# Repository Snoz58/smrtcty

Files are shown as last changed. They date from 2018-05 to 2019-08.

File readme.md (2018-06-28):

Smart Village
=============

Définition
----------

Ce projet a pour objectif la réalisation d'un système de « Smart City » à l’échelle d’un village.

Il est Open source, et basé sur le plus d'éléments open source possible, côté matériel comme logiciel.

Cette solution se présente sous la forme d'un « kit », réplicable, simple à mettre en place et à utiliser, et polyvalent.

Node / Noeuds
-------------

Cette partie du système est totalement indépendante. Il s'agit de points de relevé d'informations auto alimentés (panneau photovoltaïque) basés autour d'une carte Arduino qui transmet les données collectées par l'intermédiaire d'une liaison sans fil.

Ces nœuds permettent le captage d’information dans l’environnement (pour la version en cours de développement des capteurs concernant la qualité de l’air (Température, Pression, Humidité, Particules...) mais aussi des capteurs plus orientés qualité de l’eau (Température, Ph, niveau…).

Passerelle
----------
La passerelle centralise les informations qu’elle reçoit de la part des différents nœuds.
Elle se présente sous la forme d'un Raspberry Pi associé à un module sans fil, installé dans un bâtiment afin de bénéficier d’un accès internet et d’une alimentation électrique. Elle va récupérer les données des capteurs, et les renvoyer vers une base de donnée distante.

Plateforme de centralisation
----------------------------

Cette dernière partie du système n’est pas matérielle mais logicielle, il s’agit d’un système de tableau de bord qui va permettre de visualiser les données recueillies par le dispositif sous forme de tableau et de graphique.

Transmission Sans Fil
---------------------
Les solutions de transmission de donnée retenues pour ce projet sont toutes basées sur des technologies radio :
 * Radio « standard » 433MHz (appareils domotique, etc).
 * xBee / ZigBee.
 * LoRa, dérivé également de la technologie radio, orienté basse consommation longue portée.

Solution de transmission sans fil sera choisie en fonction des résultat obtenus lors des tests de portée et de la situation dans laquelle le système sera mis en place.

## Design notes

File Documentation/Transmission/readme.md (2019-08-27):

## Transmission sans fil

### LoRa

---

***[DOCUMENTATION MODULE ADAFRUIT RFM95W](./RFM95W.md)***

Documentation module RFM95W (ref 3072) :
https://learn.adafruit.com/adafruit-rfm69hcw-and-rfm96-rfm95-rfm98-lora-packet-padio-breakouts/using-the-rfm69-radio

Autres infos :
https://forum.arduino.cc/index.php?topic=471254.0

---

Exemples / docmentation Python :
https://learn.adafruit.com/adafruit-rfm69hcw-and-rfm96-rfm95-rfm98-lora-packet-padio-breakouts?view=all

Intro technologie LoRa (cartes, topologie, outils, ...) :
http://www.instructables.com/id/Introducing-LoRa-/

Documentation expérimentation LoRa / tests de portée :
https://www.cooking-hacks.com/documentation/tutorials/extreme-range-lora-sx1272-module-shield-arduino-raspberry-pi-intel-galileo/

Cartes spécifiques LoRa campatibles Arduino / Raspberry :
https://www.cooking-hacks.com/documentation/tutorials/lorawan-for-arduino-raspberry-pi-waspmote-868-900-915-433-mhz/

Infos LoRaWAN / Sigfox :
https://forum.arduino.cc/index.php?topic=503808.0

### xBee

---

***[DOCUMENTATION MODULE xBee](./xBee.md)***

Documentation paramétrage / utilisation logiciel XCTU :

http://www.electro-info.ovh/index.php?id=231
https://learn.sparkfun.com/tutorials/exploring-xbees-and-xctu
http://www.libelium.com/development/waspmote/documentation/x-ctu-tutorial/
https://www.digi.com/resources/documentation/Digidocs/90001456-13/tasks/t_wk_configure_xbees.htm

---

Communication longue distance avec xBee :
https://electronics.stackexchange.com/questions/1149/wireless-communication-over-long-distances

Guide modules xBee avec spécifications :
https://www.sparkfun.com/pages/xbee_guide

### Radio

---

***[DOCUMENTATION MODULE HC-12](./hc-12.md)***

Tutoriel d'utilisation du module + exemples :
https://howtomechatronics.com/tutorials/arduino/arduino-and-hc-12-long-range-wireless-communication-module/

Video + ressource commandes AT :
https://www.instructables.com/id/Long-Range-18km-Arduino-to-Arduino-Wireless-Commun/

---

***[DOCUMENTATION MODULE NRF24L01](./NRF24L01.md)***

Tutoriel d'utilisation du module + exemples :
https://howtomechatronics.com/tutorials/arduino/arduino-wireless-communication-nrf24l01-tutorial/

---

### Autres

Guide modules Bluetooth avec spécifications :
https://www.intorobotics.com/pick-right-bluetooth-module-diy-arduino-project/

Transformation int to char :
https://www.instructables.com/id/Converting-integer-to-character/

## Transmission Filaire

Communication série Arduino <-> Raspberry :
http://www.instructables.com/id/Raspberry-Pi-Arduino-Serial-Communication/

Communication Arduino <-> Raspberry sur le bus I2C :
https://www.pihomeserver.fr/2013/08/13/raspberry-pi-home-server-arduino-lier-les-deux-via-bus-i2c/

Communication Arduino <-> Raspberry via UART :
https://electrosome.com/uart-raspberry-pi-python/

# Infos Passerelle Raspberry Pi

Wiki dragino :
https://wiki.dragino.com/index.php?title=Lora_Shield

Dragino Shield cs pin :
https://www.google.fr/search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:

Gpio Python :
https://deusyss.developpez.com/tutoriels/RaspberryPi/PythonEtLeGpio/

Tuto gateway sans shield :
https://www.hackster.io/ChrisSamuelson/lora-raspberry-pi-single-channel-gateway-cheap-d57d36

Programme passerelle en C :
https://github.com/dragino/rpi-lora-tranceiver/blob/master/dragino_lora_app_w1/main.c

LoRa GPS hat wiki dragino :
https://wiki.dragino.com/index.php?title=Lora/GPS_HAT#Two_RPI_use_LoRa_to_transmit

Programme Gateway :
https://github.com/CongducPham/LowCostLoRaGw

LoRa Shield pour Arduino :
https://wiki.dragino.com/index.php?title=Lora_Shield

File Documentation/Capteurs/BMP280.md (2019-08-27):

# BMP280
Capteur de pression atmosphérique - Baromètre

## Programme

Nom du programme : BMP280.ino

```C++
#include "Seeed_BMP280.h"
#include <Wire.h>

BMP280 bmp280;

void setup()
{
  Serial.begin(9600);
  if(!bmp280.init()) {
    Serial.println("Device not connected or broken!");
  }
}

void loop()
{

  float p = bmp280.getPressure();
  float t = bmp280.getTemperature();

  Serial.print("Temp: ");
  Serial.print(t);

  Serial.print("Pressure: ");
  Serial.println(p);

  delay(1000);
}
```
## Ressources

http://gilles.thebault.free.fr/spip.php?article47

http://idehack.com/blog/tutoriel-arduino-bmp280/

https://www.tala-informatique.fr/wiki/index.php/Arduino_BMP280

https://create.arduino.cc/projecthub/SurtrTech/bmp280-measure-temperature-pressure-and-altitude-e1c857

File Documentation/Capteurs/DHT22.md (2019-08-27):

# DHT22
Cateur de température et d'humidité

## Programme :

Nom du programme : DHT21.ino
```C++
#include <Adafruit_Sensor.h>
#include <DHT.h>
#include <DHT_U.h>

#define DHTPIN            A2
#define DHTTYPE           DHT22

DHT_Unified dht(DHTPIN, DHTTYPE);

void setup() {
  Serial.begin(9600);
  dht.begin();
}

void loop() {
  // Delay between measurements.
  delay(1000);

  sensors_event_t event;  
  dht.temperature().getEvent(&event);
  if (isnan(event.temperature)) {
    Serial.println("Error reading temperature!");
  }
  else {
    Serial.print("Temperature: ");
    Serial.print(event.temperature);
    Serial.println(" *C");
  }

  // Get humidity event and print its value.
  dht.humidity().getEvent(&event);
  if (isnan(event.relative_humidity)) {
    Serial.println("Error reading humidity!");
  }
  else {
    Serial.print("Humidity: ");
    Serial.print(event.relative_humidity);
    Serial.println("%");
  }
}
```
## Ressources :

http://www.manuel-esteban.com/lire-une-sonde-dht22-avec-un-arduino/

https://projetsdiy.fr/mesure-humidite-temperature-capteur-dht11-dht22-arduino-raspberry/

http://nagashur.com/blog/2013/06/18/lire-la-valeur-dune-sonde-de-temperature-et-d%E2%80%99hygrometrie-dht11/

https://www.carnetdumaker.net/articles/utiliser-un-capteur-de-temperature-et-dhumidite-dht11-dht22-avec-une-carte-arduino-genuino/

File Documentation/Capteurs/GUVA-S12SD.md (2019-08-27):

# GUVA-S12SD
Capteur UV

## Programme
Nom du programme : GUVA-S12SD.ino

```C++
void setup()
{
  Serial.begin(9600);
}

void loop()
{
  float sensorVoltage;
  float sensorValue;

  sensorValue = analogRead(A1);
  sensorVoltage = sensorValue/1024*3.3;
  Serial.print("sensor reading = ");
  Serial.print(sensorValue);
  Serial.println("");
  Serial.print("sensor voltage = ");
  Serial.print(sensorVoltage);
  Serial.println(" V");
  delay(3000);
}
```

## Ressources

https://www.adafruit.com/product/1918

https://forums.adafruit.com/viewtopic.php?f=19&t=95381

https://cdn-shop.adafruit.com/datasheets/1918guva.pdf

http://arduinolearning.com/code/arduino-guva-s12sd-uv-sensor.php

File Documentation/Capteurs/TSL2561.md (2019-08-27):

# TSL2561
Lux sensor / Capteur de luminosité

## Programme

Nom du programme : TSL2561.ino
```C++
#include <Wire.h>
#include <Adafruit_Sensor.h>
#include <Adafruit_TSL2561_U.h>

Adafruit_TSL2561_Unified tsl = Adafruit_TSL2561_Unified(TSL2561_ADDR_FLOAT, 12345);

void setup(void)
{
  Serial.begin(9600);  

  tsl.begin();

  tsl.enableAutoRange(true);            
  tsl.setIntegrationTime(TSL2561_INTEGRATIONTIME_101MS);  

}

void loop(void)
{  

  sensors_event_t event;
  tsl.getEvent(&event);

  Serial.print(event.light); Serial.println(" lux");

  delay(250);
}
```

## Ressources
https://learn.adafruit.com/tsl2561/arduino-code

https://github.com/adafruit/Adafruit_TSL2561

https://fr.wikipedia.org/wiki/Lux_(unit%C3%A9)

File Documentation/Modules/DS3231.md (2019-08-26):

https://github.com/jarzebski/Arduino-DS3231/blob/master/DS3231_alarm/DS3231_alarm.ino

http://www.open-sensing.org/lorablog/2017/10/23/low-power-rtc-and-sleeping-processors-a-guided-walkthrough

https://github.com/JChristensen/DS3232RTC

https://forum.arduino.cc/index.php?topic=139955.0

https://forum.arduino.cc/index.php?topic=346940.75

https://forum.arduino.cc/index.php?topic=404942.0

https://forum.arduino.cc/index.php?topic=319975.0

https://forum.sparkfun.com/viewtopic.php?t=40332

https://thecavepearlproject.org/2014/05/21/using-a-cheap-3-ds3231-rtc-at24c32-eeprom-from-ebay/

https://forum.arduino.cc/index.php?topic=241491.0

https://thekurks.net/blog/2018/2/5/wakeup-rtc-datalogger

https://learn.adafruit.com/adafruit-ds3231-precision-rtc-breakout?view=all

https://arduino.stackexchange.com/questions/10516/rtc-square-wave/10561

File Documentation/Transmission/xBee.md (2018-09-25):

# XBee

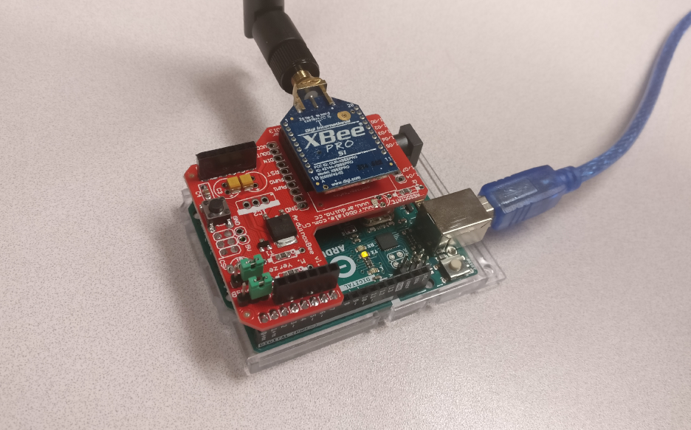
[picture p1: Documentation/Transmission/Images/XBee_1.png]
module xBee


## Paramétrage :

Les modules xBee sont différents des autres modules utilisées jusqu'à présent, ils possèdent en effet une mémoire et un firmware spécifique, avec des adresses.

Pour la configuration de ces modules, il est nécessaire d'utiliser le logiciel XCTU, fourni par DIGI (producteur des modules xBee)

Le logiciel est disponible [ici](https://www.digi.com/support/productdetail?pid=3352) dans la section ***Diagnostics,Utilities and MIBs***

* XCTU version 6.4.0 (dernière version en date)
* Legacy XCTU, version 5.2.8.6 (génération précédente)

## Problèmes rencontrés :

La plupart des tutoriels utilisent un [USB explorer ](https://www.sparkfun.com/products/11812) pour connecter le xBee à l'ordinateur. Ne possédans pas cet appareil, j'ai donc utilisé une carte arduino ([UNO](https://www.sparkfun.com/products/11021) et [MEGA](https://www.sparkfun.com/products/11061)) associé à un [shield xbee](https://www.gotronic.fr/art-module-xbee-shield-12427.htm).

J'ai donc commencé mes tests avec XCTU V6.4.0 et le module xBee connecté au shield sur l'Arduino MEGA.

La découverte des modules connecté au pc est possible avec le second bouton en haut à gauche de l'écran :

bouton discover xctu

Une popup s'ouvre alors en listant les ports COM disponibles, on selectionne celui correspondant à l'Arduino avant de cliquer sur *Next* :

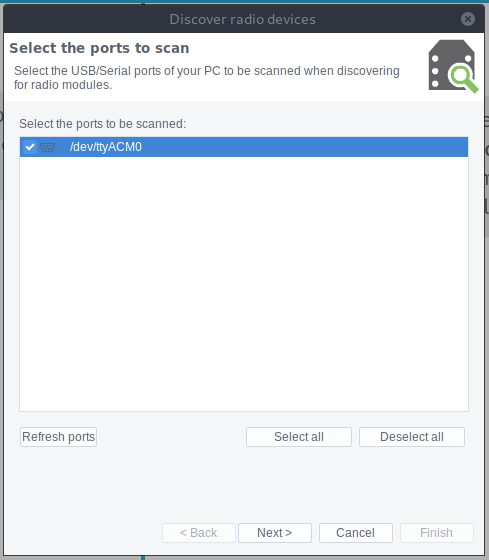
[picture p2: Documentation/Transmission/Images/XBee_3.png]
popup discover xctu


S'ouvrent alors les paramètres de recherche des modules, et on peut cliquer sur *Finish* pour lancer la recherche :

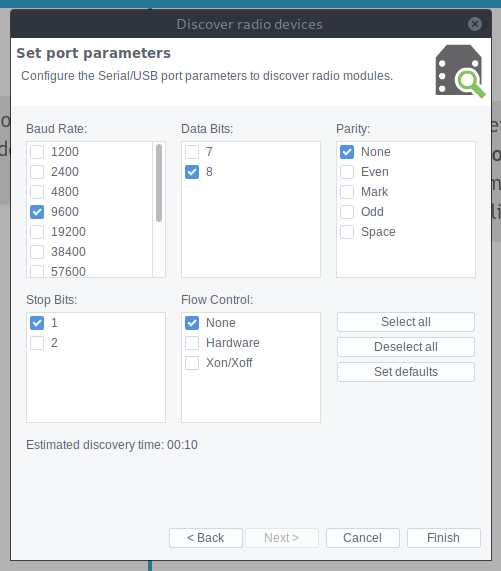
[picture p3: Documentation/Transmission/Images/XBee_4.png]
port parameters xctu


Le module devrait alors apparaître sur le côté gauche de l'écran :

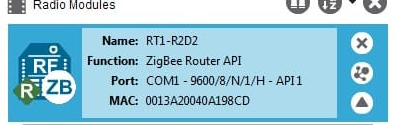
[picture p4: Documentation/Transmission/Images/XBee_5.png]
module xctu


*** Premier problème : ***

À ce moment, la carte Arduino et le module associé sont donc reconnus par le logiciel, mais les paramètres internes ne le sont pas encore, on sélectionne donc l'option *Read* :

Read xctu

Une pop up s'affiche alors en demandant de reset notre module radio :

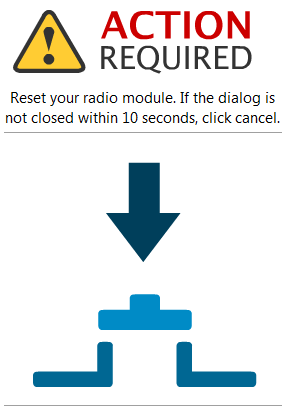
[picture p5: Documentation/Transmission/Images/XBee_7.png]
action required xctu


Cependant, ni le bouton reset ni le bouton présent sur le shield ne permettent de débloquer cet écran.

Après avoir suivi [ce tuto](https://learn.sparkfun.com/tutorials/exploring-xbees-and-xctu/troubleshooting#reset) pour reset un module xBee en connectant le pin 5 (reset) au pin 10 (GND). La LED présente sur le shield s'éteint puis se rallume, indiquant le reset du module, mais la popup reste cependant, jusqu'à se transformer en message d'erreur au bout d'un certain temps.

Apres recherche, il s'avère que les versions précédentes du logiciel ne nécessitent pas cette action, j'ai donc tenté de l'utiliser avec l'aide de [ce tuto](https://robotic-controls.com/book/export/html/14) d'utiliser la version "legacy" de xctu.

La carte Arduino sans son microcontrolleur a donc été couplé au shield dont les jumpers sont passés en mode *USB* :

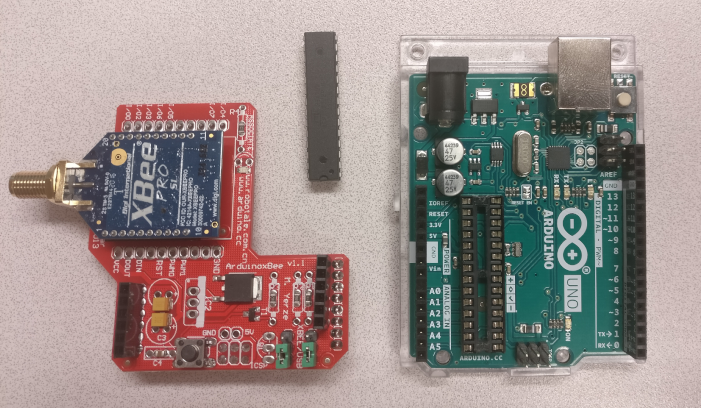
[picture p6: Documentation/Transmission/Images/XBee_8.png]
Uno sans uc


Sur le logiciel, la carte Arduino est bien reconnue par le logiciel:

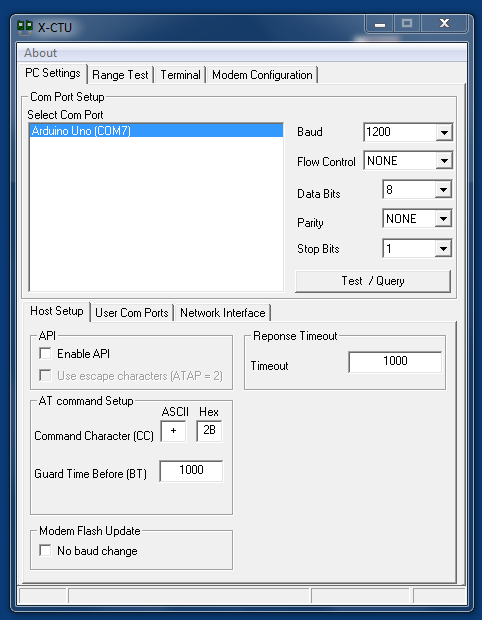
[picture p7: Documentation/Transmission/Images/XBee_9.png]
old xctu


Après avoir cliqué sur le bouton *Test / Query*  le logiciel reconnaît bien la carte et le module xBee.

Je débranche donc le montage pour le réutiliser avec le logiciel récent.

*** Deuxième problème ***

Sur le "nouveau" xctu, à la fin de la recherche de module xBee, après avoir correctement sélectionné le bon port, aucun module xBee n'est trouvé, ou bien une erreur apparaît indiquant un timeout sans que le logiciel n'ait pu récupérer les informations de la carte :

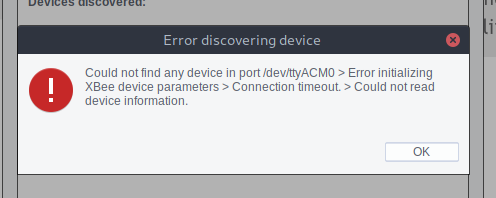
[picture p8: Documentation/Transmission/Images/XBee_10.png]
module xBee


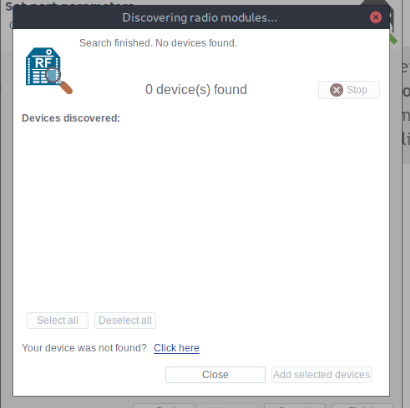
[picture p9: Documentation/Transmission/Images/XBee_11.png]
module xBee


De retour sur la version Legacy de xctu, le logiciel nous demande maintenant de reset le module xBee. Comme relevé dans le premier problème, même en connectant le pin RST à la masse, le logiciel ne se débloque pas comme il devrait :

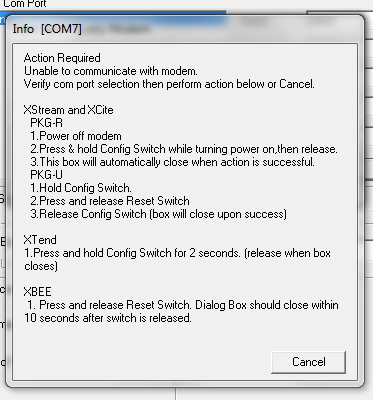
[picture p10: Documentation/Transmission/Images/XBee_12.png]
module xBee


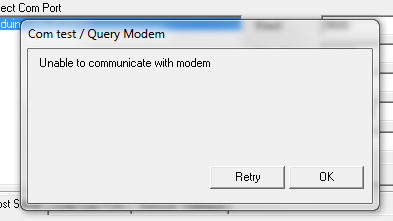
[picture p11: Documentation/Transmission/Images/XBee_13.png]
module xBee


Au final, avec la carte Arduino MEGA, ou avec la carte Arduino UNO, avec ou sans microcontrôleur, avec les jumpers en mode USB ou xBee, et sur les deux logiciels, le résultat est le même : aucune connexion n'est possible entre le logiciel et le module xBee.
J'ai également essayé avec un troisième module xBee, qui ne m'avait pas encore servi, et le résultat est resté le même.  

## xBee USB Adapter

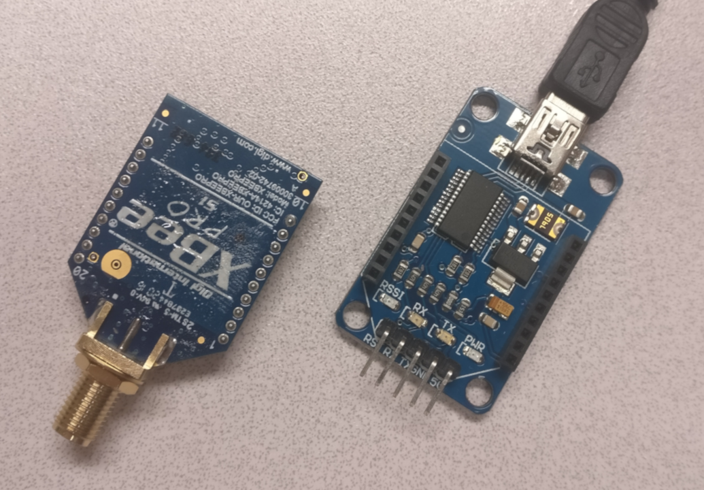
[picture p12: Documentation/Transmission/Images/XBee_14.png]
usb adapter


Unne fois le module xBee installé sur la carte, et la carte connectée au pc, on peux lancer une découverte depuis XCTU :

bouton découverte

Un appareil USB devrait alors être reconnu :

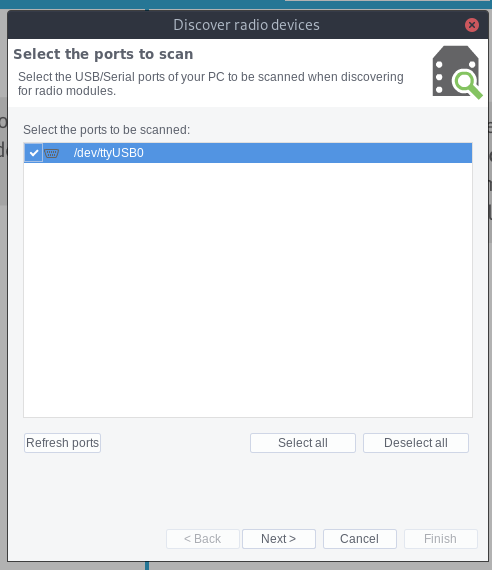
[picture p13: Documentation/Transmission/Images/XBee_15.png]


On laisse les paramètres de découverte par défaut avant de cliquer sur le bouton *Finish* :

bouton découverte

On ajoute ensuite le module trouvé par XCTU *Add selected devices* :

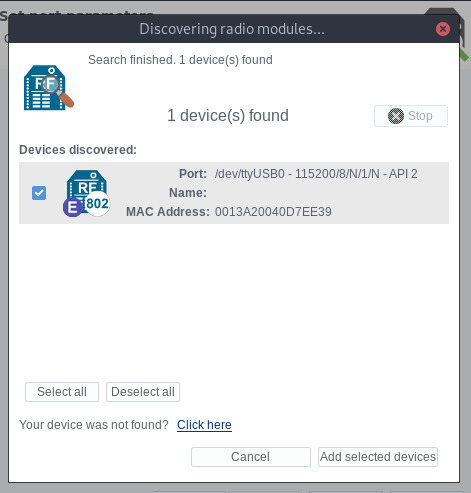
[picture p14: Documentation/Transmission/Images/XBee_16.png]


En cliquant sur le module à gauche de l'écran, une lecture des paramètres se lance automatiquement (elle peut être forcée à l'aide du bouton *Read* ) :

bouton découverte

La partie droite de l'écran présenta alors les différents paramètres du module qu'il est possible d'éditer :

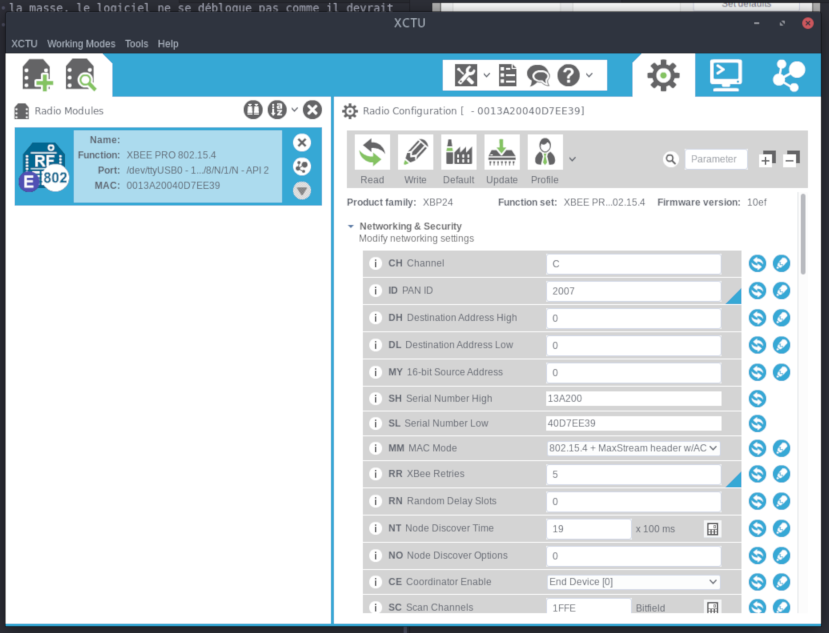
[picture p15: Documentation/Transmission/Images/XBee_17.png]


Il est possible de sauvegarder ou de charger les paramètres du xBee à partir du menu "Profile"

bouton Profil

J'ai réinitialisé les modules à leur configuration d'usine à l'aide du bouton Default

bouton Default

Pour établir une connexion entre deux modules xBee, ils doivent avoir le même canal (**CH** Channel) et la même adresse pan (Personal Area Network) (**ID** PAN ID).

Il est possible de conserver des adresses (**MY** 16-bit Source Adress) identique pour les deux modules, la transmission s'effectuera alors en broadcast.

Il est également possible de paramétrer des adresses spécifiques pour envoyer le message à un destinataire précis.
Pour cela, il faut faire correspondre les numéros de série haut et bas du destinataire (**SH** Serial Number High et **SL** Serial Number Low) avec les adresse de destination de l'expéditeur (**DH** Destination adress High et **DL** Destination Adress Low).

## Test envoi / réception

L'envoi s'effectue avec une connexion série :

Code pour l'émetteur :

```C
int timer = 0;

void setup()
{
Serial.begin (9600);
}

void loop()
{
Serial.println("Message : "+String(timer)+" Sec.");
timer++;
delay(1000); // Attendre 1s
}
```

Code pour le Récepteur :

```C
int incomingByte = 0;   

void setup() {
        Serial.begin(9600);
}

void loop() {

        if (Serial.available() > 0) {
                incomingByte = Serial.read();
                Serial.print(char(incomingByte));
        }
}
```

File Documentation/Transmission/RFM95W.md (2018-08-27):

# ADAFRUIT RFM95W
 r
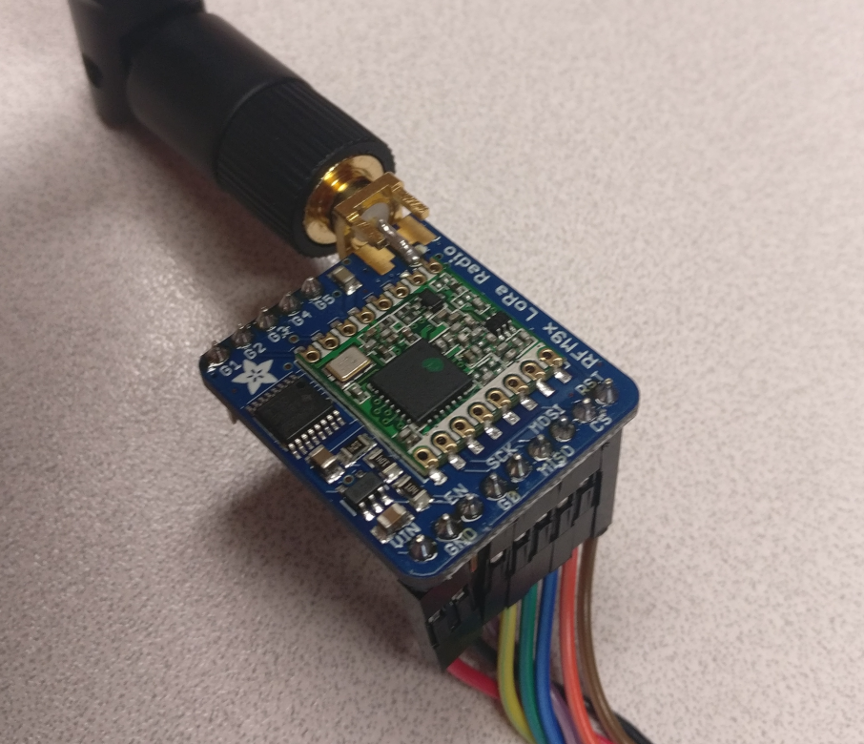
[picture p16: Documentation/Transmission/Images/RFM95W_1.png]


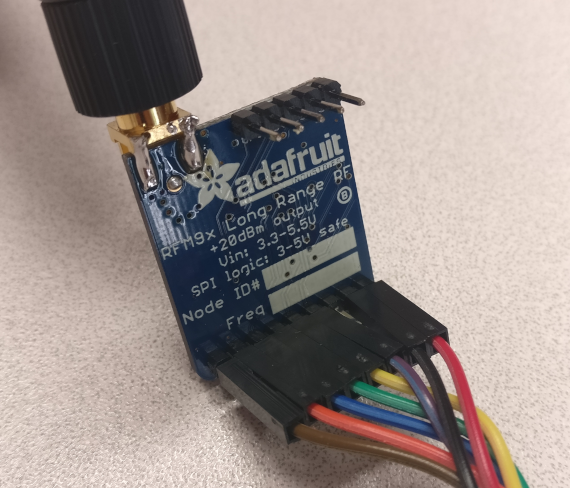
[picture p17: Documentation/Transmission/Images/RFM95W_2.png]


## Branchements

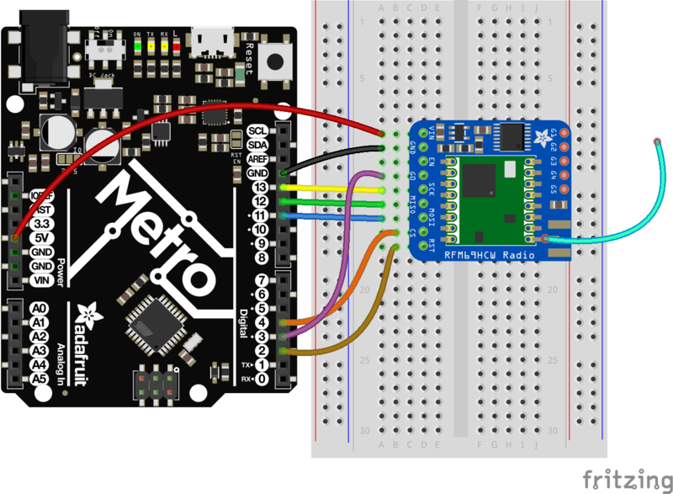
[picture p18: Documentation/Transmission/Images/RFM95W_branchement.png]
Branchements RFM95W


## Paramétrage :

Ajout de la librairie RadioHead dans l'IDE Arduino :
https://github.com/adafruit/RadioHead/archive/master.zip

## Test envoi / réception

En reprenant l'exemple de la librairie précédente (Fichier > Exemples > RadioHead > feather > Feather9x_TX), on modifie simplement les pins correspondant à notre montage dans les #define :

```C++
// Feather9x_TX
// -*- mode: C++ -*-
// Example sketch showing how to create a simple messaging client (transmitter)
// with the RH_RF95 class. RH_RF95 class does not provide for addressing or
// reliability, so you should only use RH_RF95 if you do not need the higher
// level messaging abilities.
// It is designed to work with the other example Feather9x_RX

#include <SPI.h>
#include <RH_RF95.h>

#define RFM95_CS      4
#define RFM95_INT     3
#define RFM95_RST     2
#define LED           13

// Change to 434.0 or other frequency, must match RX's freq!
#define RF95_FREQ 915.0

// Singleton instance of the radio driver
RH_RF95 rf95(RFM95_CS, RFM95_INT);

void setup()
{
  pinMode(RFM95_RST, OUTPUT);
  digitalWrite(RFM95_RST, HIGH);

  Serial.begin(115200);
  while (!Serial) {
    delay(1);
  }

  delay(100);

  Serial.println("Feather LoRa TX Test!");

  // manual reset
  digitalWrite(RFM95_RST, LOW);
  delay(10);
  digitalWrite(RFM95_RST, HIGH);
  delay(10);

  while (!rf95.init()) {
    Serial.println("LoRa radio init failed");
    while (1);
  }
  Serial.println("LoRa radio init OK!");

  // Defaults after init are 434.0MHz, modulation GFSK_Rb250Fd250, +13dbM
  if (!rf95.setFrequency(RF95_FREQ)) {
    Serial.println("setFrequency failed");
    while (1);
  }
  Serial.print("Set Freq to: "); Serial.println(RF95_FREQ);

  // Defaults after init are 434.0MHz, 13dBm, Bw = 125 kHz, Cr = 4/5, Sf = 128chips/symbol, CRC on

  // The default transmitter power is 13dBm, using PA_BOOST.
  // If you are using RFM95/96/97/98 modules which uses the PA_BOOST transmitter pin, then
  // you can set transmitter powers from 5 to 23 dBm:
  rf95.setTxPower(23, false);
}

int16_t packetnum = 0;  // packet counter, we increment per xmission

void loop()
{
  delay(1000); // Wait 1 second between transmits, could also 'sleep' here!
  Serial.println("Transmitting..."); // Send a message to rf95_server

  char radiopacket[20] = "Hello World #      ";
  itoa(packetnum++, radiopacket+13, 10);
  Serial.print("Sending "); Serial.println(radiopacket);
  radiopacket[19] = 0;

  Serial.println("Sending...");
  delay(10);
  rf95.send((uint8_t *)radiopacket, 20);

  Serial.println("Waiting for packet to complete...");
  delay(10);
  rf95.waitPacketSent();
  // Now wait for a reply
  uint8_t buf[RH_RF95_MAX_MESSAGE_LEN];
  uint8_t len = sizeof(buf);

  Serial.println("Waiting for reply...");
  if (rf95.waitAvailableTimeout(1000))
  {
    // Should be a reply message for us now   
    if (rf95.recv(buf, &len))
   {
      Serial.print("Got reply: ");
      Serial.println((char*)buf);
      Serial.print("RSSI: ");
      Serial.println(rf95.lastRssi(), DEC);    
    }
    else
    {
      Serial.println("Receive failed");
    }
  }
  else
  {
    Serial.println("No reply, is there a listener around?");
  }

}
```

Le module tente alors de communiquer en envoyant un message :

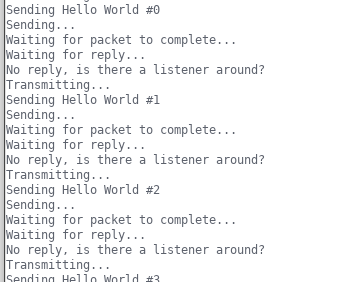
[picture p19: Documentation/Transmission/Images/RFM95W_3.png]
dd


En connectant un second module avec le code de l'exemple en réception  (Fichier > Exemples > RadioHead > feather > Feather9x_RX) avec les pins correctement configurés :

```C
// Feather9x_RX
// -*- mode: C++ -*-
// Example sketch showing how to create a simple messaging client (receiver)
// with the RH_RF95 class. RH_RF95 class does not provide for addressing or
// reliability, so you should only use RH_RF95 if you do not need the higher
// level messaging abilities.
// It is designed to work with the other example Feather9x_TX

#include <SPI.h>
#include <RH_RF95.h>

#define RFM95_CS      4
#define RFM95_INT     3
#define RFM95_RST     2
#define LED           13  

// Change to 434.0 or other frequency, must match RX's freq!
#define RF95_FREQ 915.0

// Singleton instance of the radio driver
RH_RF95 rf95(RFM95_CS, RFM95_INT);

// Blinky on receipt
#define LED 13

void setup()
{
  pinMode(LED, OUTPUT);
  pinMode(RFM95_RST, OUTPUT);
  digitalWrite(RFM95_RST, HIGH);

  Serial.begin(115200);
  while (!Serial) {
    delay(1);
  }
  delay(100);

  Serial.println("Feather LoRa RX Test!");

  // manual reset
  digitalWrite(RFM95_RST, LOW);
  delay(10);
  digitalWrite(RFM95_RST, HIGH);
  delay(10);

  while (!rf95.init()) {
    Serial.println("LoRa radio init failed");
    while (1);
  }
  Serial.println("LoRa radio init OK!");

  // Defaults after init are 434.0MHz, modulation GFSK_Rb250Fd250, +13dbM
  if (!rf95.setFrequency(RF95_FREQ)) {
    Serial.println("setFrequency failed");
    while (1);
  }
  Serial.print("Set Freq to: "); Serial.println(RF95_FREQ);

  // Defaults after init are 434.0MHz, 13dBm, Bw = 125 kHz, Cr = 4/5, Sf = 128chips/symbol, CRC on

  // The default transmitter power is 13dBm, using PA_BOOST.
  // If you are using RFM95/96/97/98 modules which uses the PA_BOOST transmitter pin, then
  // you can set transmitter powers from 5 to 23 dBm:
  rf95.setTxPower(23, false);
}

void loop()
{
  if (rf95.available())
  {
    // Should be a message for us now
    uint8_t buf[RH_RF95_MAX_MESSAGE_LEN];
    uint8_t len = sizeof(buf);

    if (rf95.recv(buf, &len))
    {
      digitalWrite(LED, HIGH);
      RH_RF95::printBuffer("Received: ", buf, len);
      Serial.print("Got: ");
      Serial.println((char*)buf);
       Serial.print("RSSI: ");
      Serial.println(rf95.lastRssi(), DEC);

      // Send a reply
      uint8_t data[] = "And hello back to you";
      rf95.send(data, sizeof(data));
      rf95.waitPacketSent();
      Serial.println("Sent a reply");
      digitalWrite(LED, LOW);
    }
    else
    {
      Serial.println("Receive failed");
    }
  }
}
```

On observe bien la communication entre les deux modules :

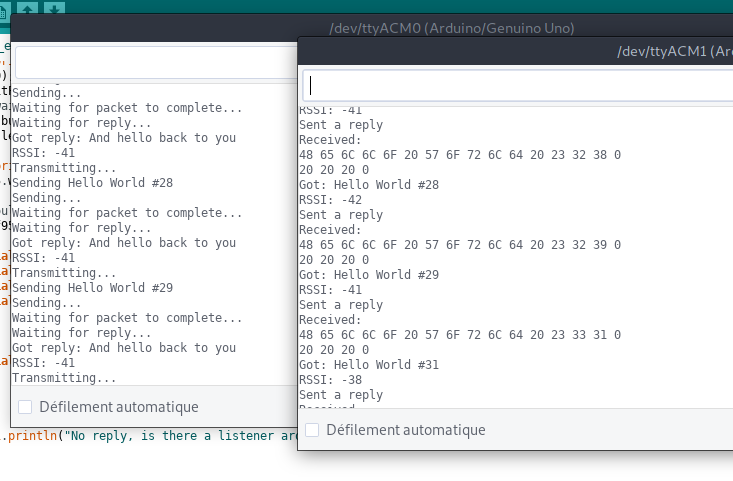
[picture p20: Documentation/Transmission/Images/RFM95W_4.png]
Communication


> /!\ Pour faire clignoter une led avec ce montage, il est necessaire d'utiliser une autre que celle de la carte, étant donné que le pin 13 est déjà utilisé par le module LoRa /!\

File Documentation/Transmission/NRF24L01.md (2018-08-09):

# ADAFRUIT NRF24L01

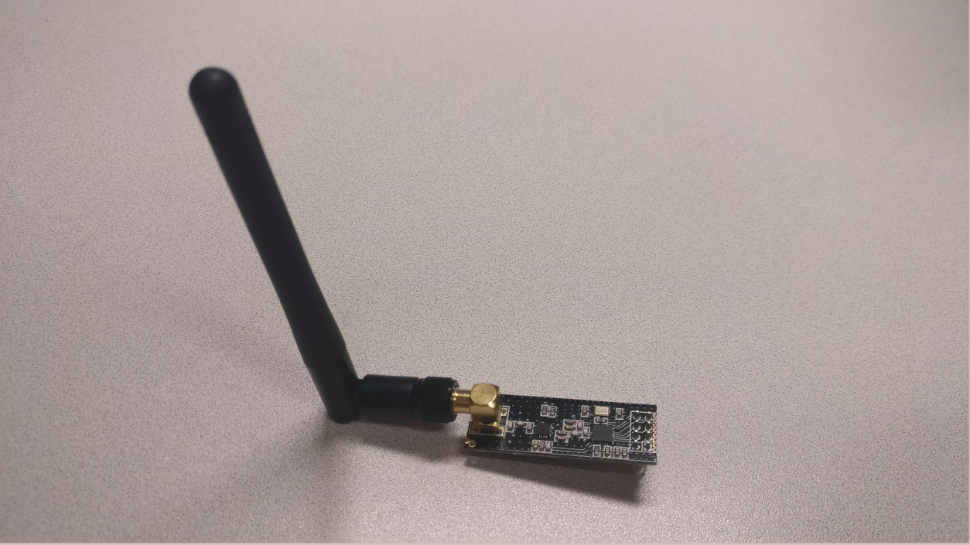
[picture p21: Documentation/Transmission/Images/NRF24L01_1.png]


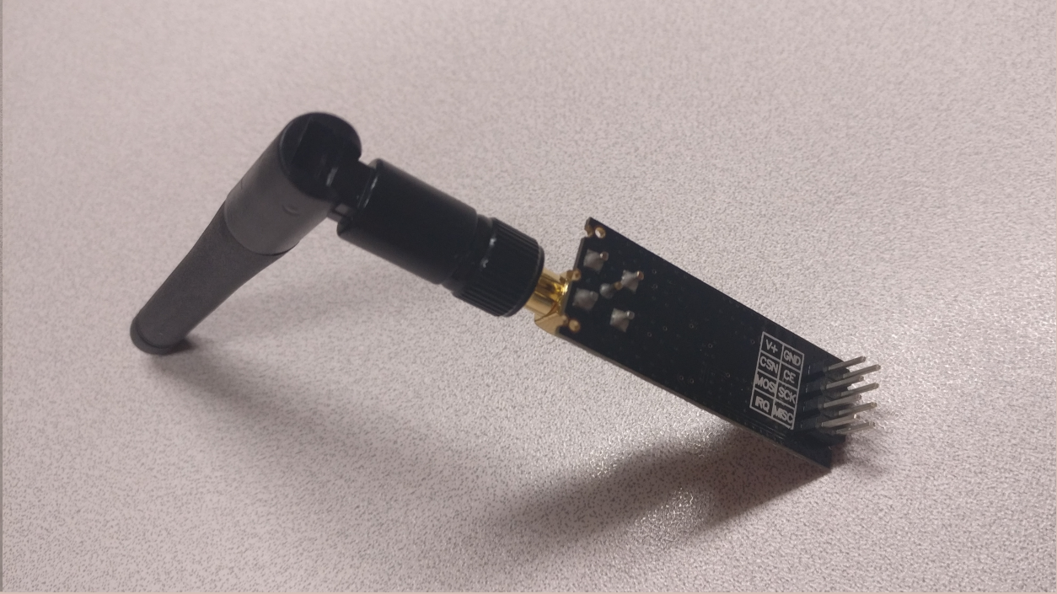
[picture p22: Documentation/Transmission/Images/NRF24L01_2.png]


## Branchements

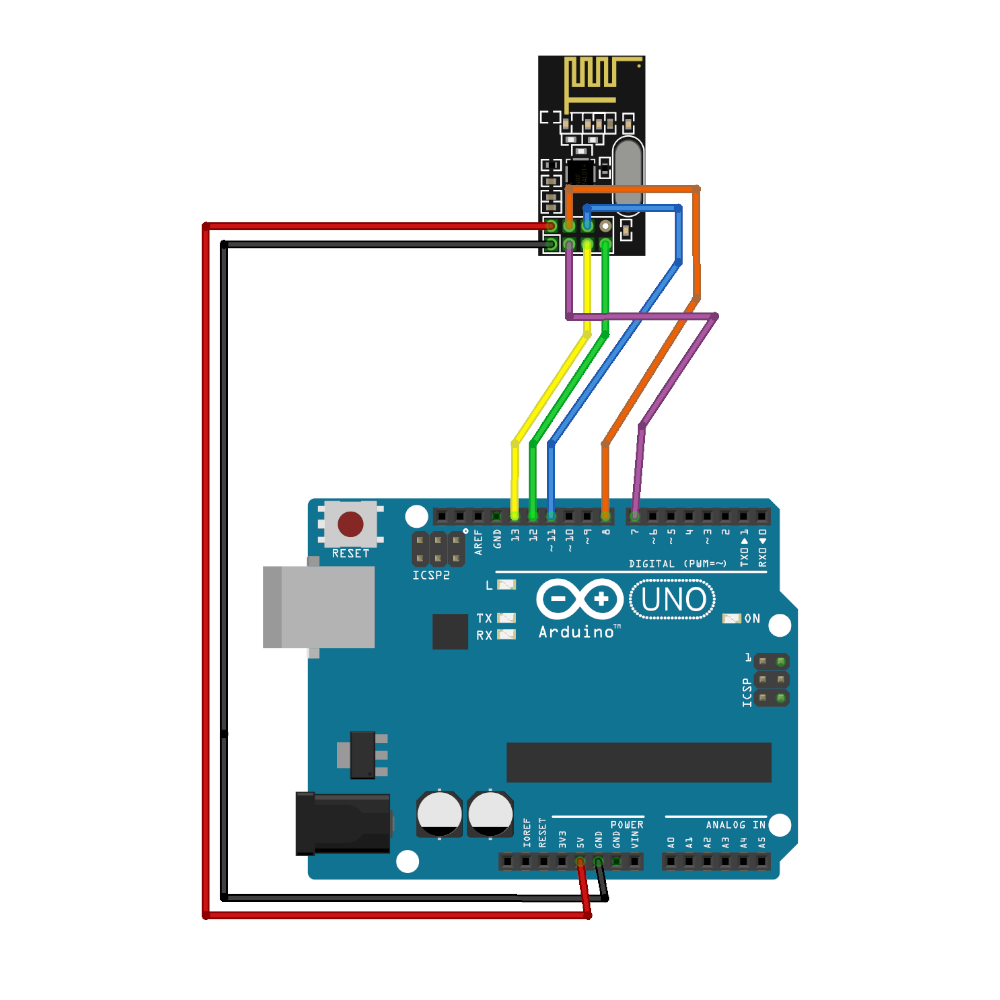
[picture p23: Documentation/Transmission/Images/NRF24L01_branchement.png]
Branchements NRF24L01


## Paramétrage :

Ajout de la librairie RF24 dans l'IDE Arduino :
https://github.com/nRF24/RF24/archive/v1.3.1.zip

On peut vérifier les caractéristique des modules avec le programme suivant :

```C
#include <SPI.h>
#include "nRF24L01.h"
#include "RF24.h"
#include "printf.h"

RF24 radio( 7, 8 );

void setup()
{
  Serial.begin( 115200 );
  printf_begin();
  radio.begin();
  radio.printDetails();
}

void loop(){}
```

Qui nous renvoie les informations dans le moniteur série :

```
STATUS		 = 0x0e RX_DR=0 TX_DS=0 MAX_RT=0 RX_P_NO=7 TX_FULL=0
RX_ADDR_P0-1	 = 0x3130303030 0xc2c2c2c2c2
RX_ADDR_P2-5	 = 0xc3 0xc4 0xc5 0xc6
TX_ADDR		 = 0xe7e7e7e7e7
RX_PW_P0-6	 = 0x20 0x00 0x00 0x00 0x00 0x00
EN_AA		 = 0x3f
EN_RXADDR	 = 0x03
RF_CH		 = 0x4c
RF_SETUP	 = 0x01
CONFIG		 = 0x0e
DYNPD/FEATURE	 = 0x00 0x00
Data Rate	 = 1MBPS
Model		 = nRF24L01+
CRC Length	 = 16 bits
PA Power	 = PA_MIN
```

## Test envoi / réception

Code pour l'émetteur :

```C
/*
* Arduino Wireless Communication Tutorial
*     Example 1 - Transmitter Code
*                
* by Dejan Nedelkovski, www.HowToMechatronics.com
*
* Library: TMRh20/RF24, https://github.com/tmrh20/RF24/
*/
#include <SPI.h>
#include <nRF24L01.h>
#include <RF24.h>
RF24 radio(7, 8); // CE, CSN
const byte address[6] = "00001";
void setup() {
  Serial.begin(9600);
  radio.begin();
  radio.openWritingPipe(address);
  radio.setPALevel(RF24_PA_MIN);
  radio.stopListening();
}

char text[10] = "";
int num = 0;

void loop() {
  for (int i=0; i<sizeof(text); i++){
    Serial.print(i);
    Serial.println(text[i]);
  }
  String(num).toCharArray(text,2);
  num = !num;
  radio.write(&text, sizeof(text));
  Serial.println(text);
  delay(1000);
}
```

Code pour le récepteur :

```C
/*
* Arduino Wireless Communication Tutorial
*       Example 1 - Receiver Code
*                
* by Dejan Nedelkovski, www.HowToMechatronics.com
*
* Library: TMRh20/RF24, https://github.com/tmrh20/RF24/
*/
#include <SPI.h>
#include <nRF24L01.h>
#include <RF24.h>
RF24 radio(7, 8); // CE, CSN
const byte address[6] = "00001";
void setup() {
  pinMode(A1, OUTPUT);
  Serial.begin(9600);
  radio.begin();
  radio.openReadingPipe(0, address);
  radio.setPALevel(RF24_PA_MIN);
  radio.startListening();
}
void loop() {
  if (radio.available()) {
    char text[32] = "";
    radio.read(&text, sizeof(text));
    if (text[0] == '1'){
      Serial.println("LEDON");
      digitalWrite(A1, HIGH);
    }
    else {
      Serial.println("LEDOFF");
      digitalWrite(A1, LOW);
    }
    Serial.println(text);
  }
}
```

On récupère bien les informations transmises :

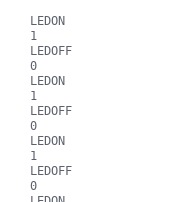
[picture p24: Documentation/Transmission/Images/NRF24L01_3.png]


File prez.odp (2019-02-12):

## SmartVillages


## Projet

- Basé sur des technologies open source
- Personnalisable
- Faible coût

## Polyvalent

- Utilisation de carte programmables
- Nombreux capteurs disponibles
- Grand support (communauté)


## Projet


## Récupération

- Arduino
- Capteurs autonomes
- Personnalisables


## Centralisation

- Raspberry pi
- Centralisation des données
- Envoi sur une base de donnée distante


## Sauvegarde et affichage

- En ligne
- Tableau de bord
- Open data


## SmartVillages

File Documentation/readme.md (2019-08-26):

# Documentation

## Exemples

Site de l'association la ville intelligente citoyenne (LVIC) :
https://www.lavilleintelligentecitoyenne.com/nos-actions

Article Sur les Smart Villages :
https://www.villeintelligente-mag.fr/Les-petites-communes-peuvent-aussi-etre-%C2%A0smart%C2%A0_a441.html

Cas de Saint Sulpice, "Smart village", tableau de bord :
https://saint-sulpice.aliotys.com/#/Tableau-de-bord/Grand-public-Display-31

## Prestataires

Alkante, création de tableau de bord personnalisés :
https://www.alkante.com/alkante

Wi6labs, mise en place d'un réseau de capteurs / IOT :
http://www.wi6labs.com/

## Capteurs

Capteurs de gaz :
https://snootlab.com/lang-en/51-gas

Capteur de particules avec une autre carte contrôleur :
http://geojournalism.org/2014/04/dustduino-arduino-uno-edition/

Capteur de particules avec tests :
http://www.howmuchsnow.com/arduino/airquality/grovedust/

Sonde DHT22 :
http://www.manuel-esteban.com/lire-une-sonde-dht22-avec-un-arduino/

## Interface

Popup sur la carte OpenLayers :
https://connect.boundlessgeo.com/docs/suite/sdk/latest/api/InfoPopup.html

Export en image de Charts :
https://stackoverflow.com/questions/20206038/converting-chart-js-canvas-chart-to-image-using-todataurl-results-in-blank-im
http://jsfiddle.net/KSgV7/585/

Exemples des différents schémas :
http://tobiasahlin.com/blog/chartjs-charts-to-get-you-started/#1-bar-chart

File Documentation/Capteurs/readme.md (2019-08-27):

Liste des Capteurs

Température - Thermomètre (DHT22)
[Documentation DHT22](./DHT22.md)

Humidité - Humidimètre (DHT22)
[Documentation DHT22](./DHT22.md)

Pression - Baromètre (BMP280)
[Documentation BMP280](./BMP280.md)

Luminosité - Luxmètre (TSL2561)
[Documentation TSL2561](./TSL2561.md)

UV - Capteur d'UV (GUVA-S12SD)
[Documentation GUVA-S12SD](./GUVA-S12SD.md)

Particules - Capter de particules (différents modèles)
[Documentation DHT22](./particules.md)

Ph - PH-mètre
[Documentation PH](./PH.md)

Niveau d’eau - Capteur à ultrason
[Documentation Niveau](./niveau.md)

Température de l’eau - Thermomètre
[Documentation DHT22](./DHT22.md)

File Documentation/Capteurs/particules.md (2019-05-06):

Programme test "DustDuino" avec analyse et transformation des unités en ug/m3 : 
https://github.com/vjpixel/DustDuinoSMS/blob/master/DustDuinoSMS.ino

Exemple d'utilisation du captur (code arduino) : 
https://github.com/selfbuilt/ppd42ns-example-code/blob/master/particle_meter/particle_meter.ino

Application de l'exemple visualisation de la qualité de l'air : 
http://www.howmuchsnow.com/arduino/airquality/grovedust/

Expérimentation du capteur sur la qualité de l'air en Inde : 
https://indiaairquality.com/2014/12/14/building-pickle-jr-the-low-cost-networked-pm2-5-monitor-part-2/

## OpenData

Mise a dispo des données sur la qualité de l'air en france : 
https://www.data.gouv.fr/fr/datasets/mise-a-disposition-de-donnees-de-qualite-de-lair-sur-la-france-www-prevair-org-1/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

Notice d'utilisation des données mises à disposition : 
https://static.data.gouv.fr/resources/donnees-temps-reel-de-mesure-des-concentrations-de-polluants-atmospheriques-reglementes-1/20180919-090120/mise-a-disposition-de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

Document xml : 
https://static.data.gouv.fr/resources/donnees-temps-reel-de-mesure-des-concentrations-de-polluants-atmospheriques-reglementes-1/20190214-083004/fr-2019-e2-2019-2019-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

## Spécifications techniques

Docuentation du capteur avec pinout des broches : 
https://github.com/mozilla-sensorweb/sensorweb-wiki/wiki/Shinyei-PPD42-Particle-Sensor

Analyse des composants et du fonctionnement du capteur (démontage et rétro ingénierie : 
http://takingspace.org/wp-content/uploads/ShinyeiPPD42NS_Deconstruction_TracyAllen.pdf

Prototype avec modification du capteur pour une meilleure précision des relevés : 
https://geojournalism.org/2014/04/dustduino-arduino-uno-edition/

Spécifications techniques du capteur  PPD42NJ : 
https://publiclab.org/system/images/photos/000/010/161/original/Spec_PPD42NJ_Eng_SPP13001V00_20130319.pdf

Page produit de la société conceptrice du capteur : 
https://www.shinyei.co.jp/stc/eng/optical/main_ppd42.html

Infos / documentation sur le capteur groove (le même que celui utilisé) : 
https://www.mouser.com/ds/2/744/Seeed_101020012-1217636.pdf

## Fonctionnement des capteurs

Infos sur le fonctionnement des capteurs de particules : 
https://www.respire-asso.org/le-capteur-de-particules-fines-pour-les-nuls/

Comparaif entre deux types de capteurs de particules différents (dont celui utilisé) : 
https://aqicn.org/sensor/shinyei/fr/

## Infos Particules

Page wikipedia sur les particules en suspension dans l'air : 
https://fr.wikipedia.org/wiki/Particules_en_suspension

Documentation particules et particules fines :
http://www.irceline.be/fr/documentation/faq/quappelle-t-on-particules-fines

Infos sur les caractéristiques des particules : 
http://hmf.enseeiht.fr/travaux/CD1011/bei/beiere/groupe5/node/71

Infos sur les particules, leur analyse et leurs sources : 
https://www.respire-asso.org/particules-en-suspension-pm10-pm-25/

Infos du laboratoire centra de surveillance de la qualité de l'air sur les caractéristiques des particules : 
https://www.lcsqa.org/system/files/drc-10-111579-13360_veille_etudes_de_sources_vf.pdf

Synthèse des connaissances sur les particules en suspension dans l'air et des travaux d'AirParif sur ces polluants : 
https://www.airparif.asso.fr/_pdf/publications/biblio_particules_081022.pdf

Etude de la composition des particules dans l’air de Saint-Malo :
https://www.airbreizh.asso.fr/voy_content/uploads/2018/04/st-malo_particules_2010.pdf

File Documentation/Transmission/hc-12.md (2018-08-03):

# HC-12

module HC-12

module HC-12

## Branchements :

Branchement module

## Paramétrage :

```C
//HC-12 AT Commander
//Autor Tom Heylen tomtomheylen.com
//The HC-12 commander mode runs at baud rate 9600

#include <SoftwareSerial.h>

SoftwareSerial mySerial(2, 3); // RX, TX

void setup() {
  Serial.begin(9600);
  Serial.println("Enter AT commands:");
  mySerial.begin(9600);
}

void loop(){
  if (mySerial.available()){
    Serial.write(mySerial.read());
  }
  if (Serial.available()){
    mySerial.write(Serial.read());
  }
}
```
Le code précédent permet de lire les paramètres de la carte et de les modifier à l'aide de commandes AT ([Commandes Hayes](https://fr.wikipedia.org/wiki/Commandes_Hayes))

Principales commandes :

| | Commande | Infos |
| --- | --- | --- |
| Afficher les paramètres | AT+RX | Renvoie tout les paramètres de la carte dans le moniteur série |
| Changer le débit | AT+Bxxxx | Avec xxxx la valeur du débit (1200bps, 2400bps, 4800bps, 9600bps, 19,200bps, 38,400bps, 57,600bps, ou 115,200bps). La valeur par défaut est 9600bps. |
| Changer le canal | AT+Cxxx  | Avec xxx la valeur entre 001 et 127 chaque ajout est un incrément de 400KHz. Par défaut à 001 (433.4MHz), il est recommandé de ne pas dépasser 100. |
| Changer le mode de fonctionnement | AT+FUx | Avec x entre 1 et 4. Pour établir une communication entre deux modules, il est nécessaire qu'ils soient réglés sur le me mode de transmission et sur le même débit. |

À la commande :
```
AT+RX
```
On a comme réponse :
```
OK+B9600
OK+RC001
OK+RP:+20dBm
OK+FU3
```
On va donc changer le mode de transmission en "FU4" pour obtenir la meilleur postée possible :
```
AT+FU4
```
Notre réponse :
```
OK+FU4,B1200
```
Vérification de la prise en compte des modifications :
```
AT+RX
```
Le débit et le mode de transmission ont bien été modifiés (à effectuer sur tous les modules pour assurer leur compatibilité) :
```
OK+B1200
OK+RC001
OK+RP:+20dBm
OK+FU4
```
## Test envoi / réception

Le programme suivant :
```C
//HC-12 messenger send/receive
//autor Tom Heylen tomtomheylen.com

#include <SoftwareSerial.h>

SoftwareSerial mySerial(2, 3); //RX, TX

void setup() {
  Serial.begin(1200);
  mySerial.begin(1200);
}

void loop() {

  if(Serial.available() > 0){//Read from serial monitor and send over HC-12
    String input = Serial.readString();
    mySerial.println(input);    
  }

  if(mySerial.available() > 1){//Read from HC-12 and send to serial monitor
    String input = mySerial.readString();
    Serial.println(input);    
  }
  delay(20);
}
```
permet de tester la bonne communication entre deux modules sans fil. En connectant deux Arduino équipés chacune d'un module à un ordinateur, on peut, par l'intermédiaire des moniteurs série de deux instances de l'IDE Arduino, envoyer des informations de l'un à l'autre et inversement.

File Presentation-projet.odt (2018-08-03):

Smart Village

## Définition

Système de « Smart City » à l’échelle d’un village.

Système Open source, basé sur des éléments eux aussi open source, autant du côté matériel (Arduino, Raspberry pi, …) que du côté logiciel (OpenStreetMaps, Bootstrap, Charts …).

Cette solution a également pour objectif d’être réplicable, et simple à mettre en place et à utiliser, avec pas ou peu d’interaction nécessaire.

Création d’un « kit » adapté aux demande des collectivités intéressées

## Node / Noeuds

Cette partie du système est indépendante, elle est auto alimentée et communique avec les autres éléments par une liaison sans fil.

Ces nœuds permettent le captage d’information dans l’environnement (pour la version en cours de développement des capteurs concernant la qualité de l’air (Température, Pression, Humidité, Particules...) mais aussi des capteurs plus orientés qualité de l’eau (Température, Ph, niveau…).

## Passerelle

La passerelle centralise les informations qu’elle reçoit de la part des différents nœuds.

Elle est installée dans un bâtiment du conseil départemental (Collège par exemple) afin de bénéficier d’un accès internet et d’une alimentation électrique et va récupérer les données des capteurs, avant de les envoyer vers une base de donnée.

## Plateforme de centralisation

Cette dernière partie du système n’est pas matérielle mais logicielle, il s’agit d’un système de tableau de bord qui va permettre de visualiser les données recueillies par le dispositif sous forme de tableau et de graphique.

## Transmission Sans Fil

Les solutions de transmission de donnée retenues pour ce projet sont toutes basées sur des technologies radio :

- Radio « standard » 433MHz (appareils domotique, etc)
- xBee / ZigBee, protocole dérivé de la radio, optimisé pour la portée
- LoRa, dérivé également de la technologie radio, orienté basse consommation longue portée

Solution de transmission sans fil sera choisie en fonction des résultat obtenus lors des tests et de la situation dans laquelle le système sera mis en place.


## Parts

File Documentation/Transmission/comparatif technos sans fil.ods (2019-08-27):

Module | Infos | Portée | Mise en place | Compatibilité | Prix | Disponibilité | Avantages | Inconvénients | Lien
Radio
HC-12 |  | 1-2Km | Simple / Moyenne | Modules avec documentation pour Arduino et Raspberry | ~ 4€ / Unité (chine) |  | Simple et abordable | Fréquence des 433MHz utilisée par tout et n’importe quoi, risque de « brouillage » du signal par d’autres appareils | https://www.ebay.com/itm/433Mhz-HC-12-SI4463-Wireless-Serial-Port-Module-1000m-Replace-Bluetooth-TOP-/401051275954
HC-11 |  | 150-300m | Identique HC |  |  |  |  |  | https://www.elecrow.com/434mhz-serial-rf-module-hc11-140m-p-873.html
UM-12 |  | ~ 1Km | Moyenne | Pas / Peu de doc pour raspberry ni arduino |  |  | Véritable antene |  | https://www.sparkfun.com/products/retired/560
LoRa
LORA32U4 |  | 1-7Km | Moyenne / Compliquée
SX1278 |  | 1Km |  |  |  |  |  | Cartes chinoises
SX1272 |  | 1Km |  |  |  |  | Carte utilisée dans libelium (possibilité de la récupérer?)
Émetteur-Récepteur Longue Portée LoRa | Basé sur la puce RFM98W | « Extrèmement longue » |  |  | 17,00 € |  |  |  | https://www.robotshop.com/eu/fr/blindage-emetteur-recepteur-longue-portee-lora-433-mhz.html
RFM95w | Module souvent utilisé dans des shields
Module radio FireBeetle | Basé sur SX127x | ~ 1Km |  | Pas de doc pour raspberry pi | 18,00 € |  | Carte, Headers et Antenne inclus | Peu de documentation
Chistera-Pi |  |  |  | Concu pour raspberry pi | 52,00 €
Bluetooth
HC-05 |  | ~9m | Simple / moyenne | Compatible avec n‘importe quel module Bluetooth maître | 13,50 € |  |  | Faible portée | http://www.conrad.fr/ce/fr/product/096819/Module-de-transmission-HC-05-Bluetooth-Velleman-VMA302-adapt-aux-cartes-Arduino-1-pcs
HC-06 |  |  |  |  | 23,00 € |  | Mêmes caractéristiques que HC-05 + possibilité De configuration en master |  | https://www.robotshop.com/eu/fr/module-bluetooth-hc-06.html
BLE Link Bee |  | 60m | Moyenne |  | 17,00 € |  |  | Portée théorique intéressante,mais le bluetooth peut vite perdre son signal selon l’environnement | https://www.robotshop.com/eu/fr/bluetooth-ble-link-bee.html
BLEduino EF01021 | Basé Sur BLE Mini | 50m |  |  | 34€ (Avec carte Arduino) |  | Module directement intégré dans la carte |  | https://www.gotronic.fr/art-carte-bleduino-ef01021-23463.html
BlueSMiRF |  | 100m |  |  | 25,00 € |  |  |  | https://www.robotshop.com/eu/fr/modem-bluetooth-bluesmirf-silver.html
Shield Bluetooth with RN-42 | Même puce que le BlueSmirf | 20m |  |  |  |  | Simple d’utilisation : shield à poser sur l’arduino | Faible portée
Wifi
ESP8266 |  | ~ 50-100m (portée moyenne du WiFi Dépendant de l’environnement) | Simple / moyenne | Nécessite une passerelle Wifi ou une carte Wifi sur le raspberry | 8,00 € | GoTronic | Simple à mettre en place, documentée, abordable, peu de pin utilisés |  | https://www.gotronic.fr/art-module-wifi-serie-esp8266-113990084-23666.htm
Easy Wifi EF02036 | Basé sur CC3000 de TI Bus STI |  | Moyenne |  | 38,00 € | GoTronic | Port micro SD pour stockage en local | Prix élevé / Pas de DHCP | https://www.gotronic.fr/art-shield-easy-wifi-ef02036-23478.htm
Wifi DEV12071 |  |  |  |  | // | GoTronic |  | Prix élevé | https://www.gotronic.fr/art-shield-wifi-dev12071-21539.htm
Wifi V1.1 103030027 | Basé sur WIZnet Fi250 |  |  |  | 50,00 € |  |  |  | https://www.gotronic.fr/art-shield-wifi-v1-1-103030027-24848.htm
GPRS |  |  |  |  |  |  |  | Consommation électrique importante
Arduino GSM V2 | Solution officielle Arduino | Infinie dans la limite de l’accès au réseau | Moyenne / Compliquée | Les bandes de communication du FAI doivent êtres Compatibles avec le module | 80€ + forfait |  |  | Cher (Module + abonnement mensuel), basé sur le réseau d’un tiers | https://www.robotshop.com/eu/fr/blindage-arduino-gsm-v2-connecteur-antenne.html
SIM900A |  |  |  |  | 10-30€ (chine) + forfait |  |  | Abonnement nécessaire, plus compliqué à répliquer | https://www.amazon.fr/RHDZQ-Conseil-D%C3%A9veloppement-Transmission-SIM900A/dp/B074H7NNGQ
SIM800L |  |  |  |  | 3-20€ (chine) + forfait |  | plus petit que SIM900 + support bluetooth et FM |  | https://www.amazon.fr/Sim800l-Quadribande-Embarqu%C3%A9e-Antenne-Arduino/dp/B01FQPLG9W
{PORTÉE TROP FAIBLE} NFC |  | 10cm
Zigbee / Xbee
XBee Pro 50mW Series 2 | 2.4GHz | 1 mile ~ 1.5Km | Moyenne | Hats et modules adaptateurs pour utilisation sur Arduino et Raspberry |  |  | Bonne documentation Protocole Xbee connu et documenté | Parfois difficile à trouver (particulièrement les cartes en 900MHz)
XBee Pro 63mW Series 2B | 2.4GHz | 1 mile ~ 1.5Km |  |  | 21,00 € |  |  |  | https://www.amazon.fr/Module-XBee-S%C3%A9rie-2C-XB24CZ7WIT-004/dp/B01EYKUYBG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
XBee Pro 60mW Series 1 | 2.4GHz | 1 mile ~ 1.5Km |  |  | 42,00 € |  |  |  | https://www.robotshop.com/eu/fr/module-emetteur-recepteur-xbee-pro-antenne-a-fil.html
XBee Pro 900 | 900MHz | 6-28 miles ~ 9-45Km
XTend 900 1W | 900MHz | 40 miles ~65Km
Solutions basées sur des réseaux existants :
LoRaWan |  | Dépend de la couverture de la zone |  |  | Modules + Abonnement pour utiliser le réseau |  | Portée | Nécessite une bonne couverture / moins adaptable que d’autres solutions / dépendance à un tiers
Sigfox |  | Dépend de la couverture de la zone |  |  | //

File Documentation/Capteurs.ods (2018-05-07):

 | Type de données | Unité | Prix | URL
Environnement – Météo
 | Température | Degrés
 | Humidité | Pourcentage
 | Pression atmosphérique | Pascal
 | Luminosité / ensoleillement | Pourcentage
 | Vitesse du vent | Km/h
Gaz
 |  |  |  | https://www.gotronic.fr/cat-gaz-1134.htm
 | Hydrogène | H2
 | Monoxyde de carbone | CO
 | Méthane | CH4
 | Dioxyde de carbone | CO2
 | Oxygène | O2
 | Dioxyde d’azote | NO2
 | Dihydrogène | H2
 | Particules
Eau
 | Ph | Ph
 | Niveau | cm
 | Température de l’eau | Degrés
Autres
 | Son
 | Horloge temps réel | /
 | GPS | Coordonnées
 | Accéléromètre | /
 | Présence / mouvement | /

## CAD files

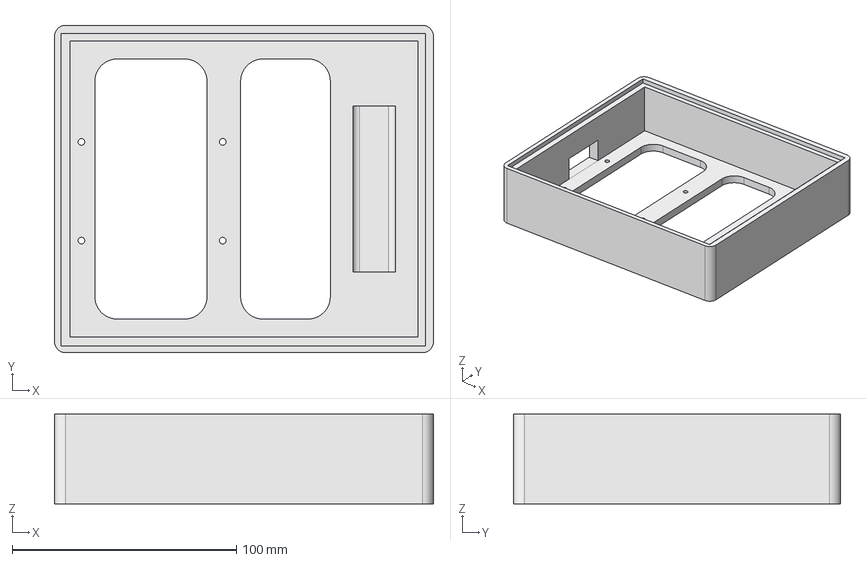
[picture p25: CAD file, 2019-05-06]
3D/Boitier demo salons/Panneau_Solaire.FCStd
169.0 x 146.0 x 40.0 mm

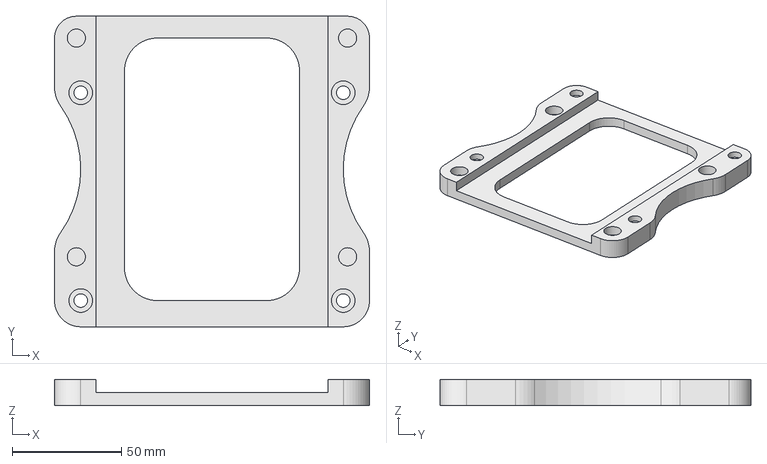
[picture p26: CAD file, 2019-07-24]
3D/fix-bride.FCStd
144.0 x 142.0 x 12.0 mm

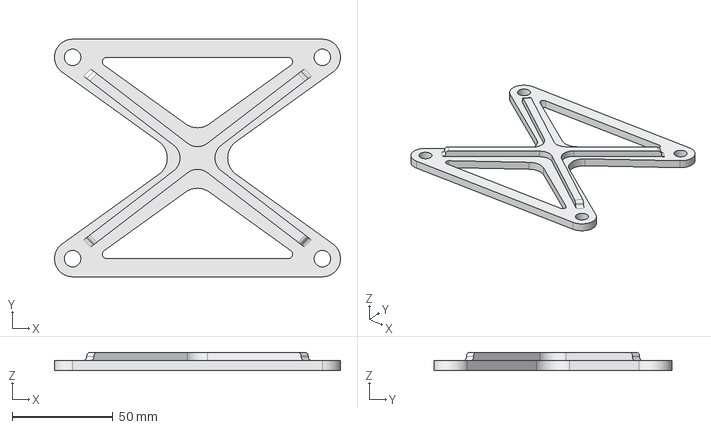
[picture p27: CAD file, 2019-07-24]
3D/bride_v2.FCStd
142.0 x 118.0 x 9.00 mm

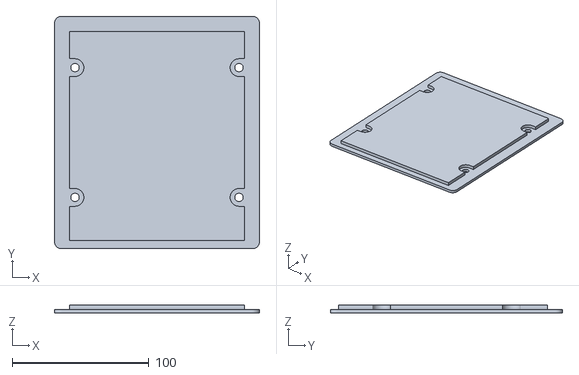
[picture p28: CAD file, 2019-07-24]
3D/arriereV2fin.stl
150.0 x 170.0 x 5.50

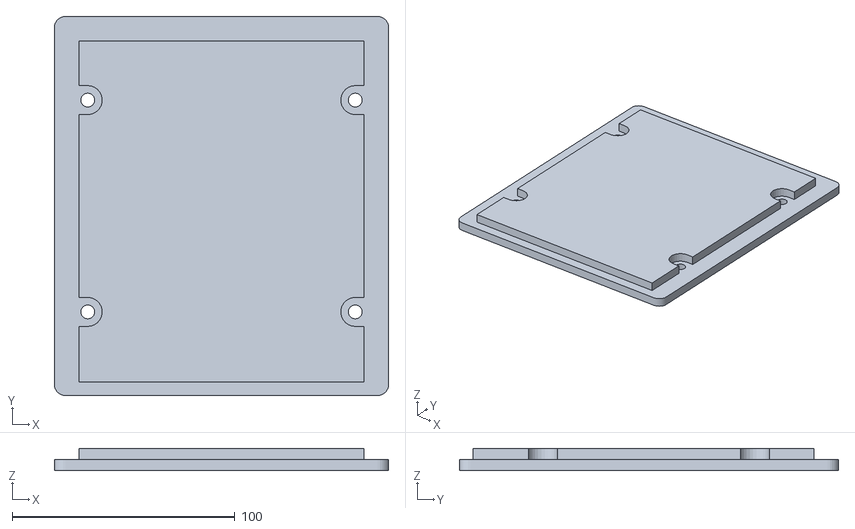
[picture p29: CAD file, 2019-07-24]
3D/arriereV2.stl
150.0 x 170.0 x 10.0

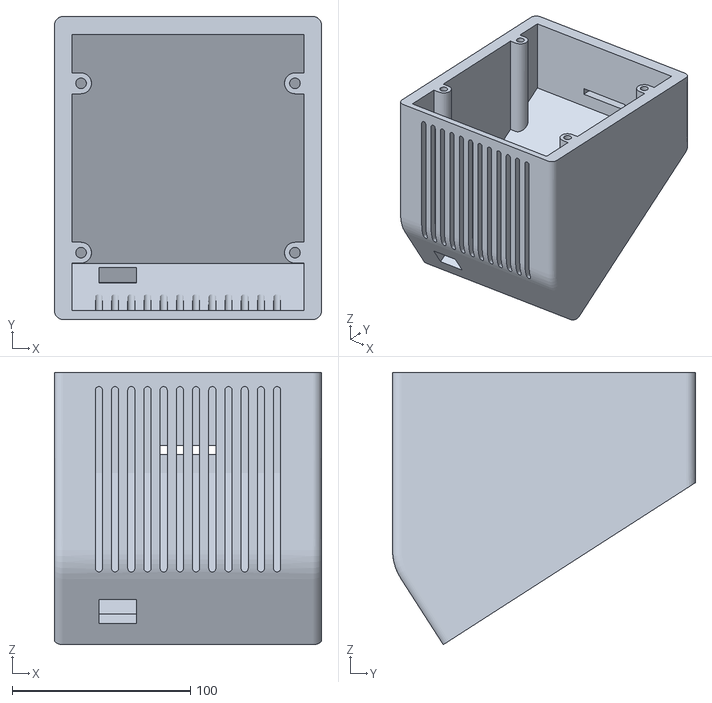
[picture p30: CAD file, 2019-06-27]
3D/bOITIERMODIF.stl
150.0 x 170.0 x 152.8

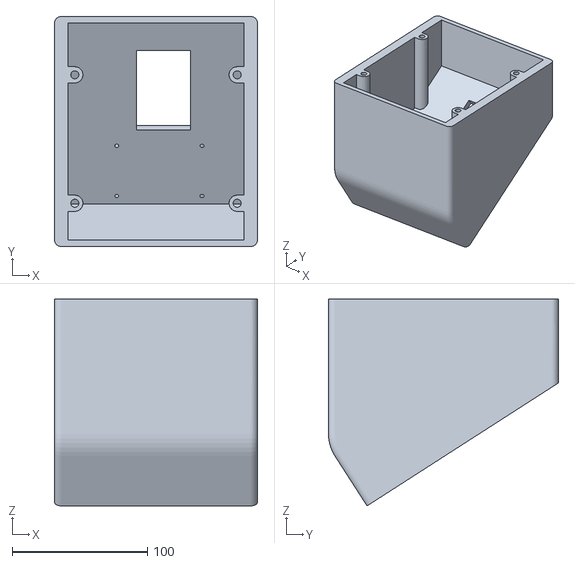
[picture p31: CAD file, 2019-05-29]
3D/lormes1.stl
150.0 x 170.0 x 152.8

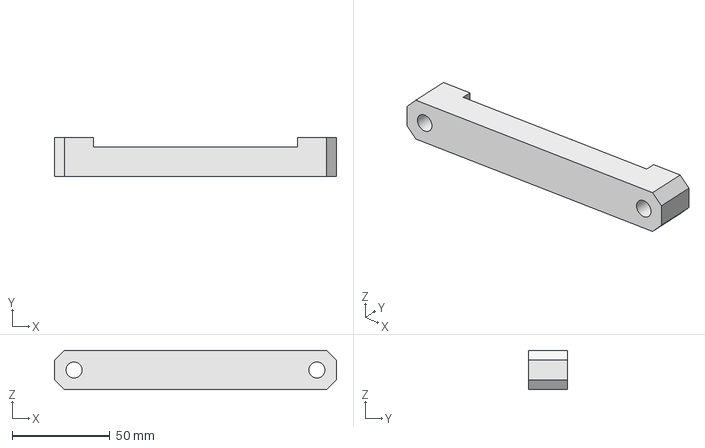
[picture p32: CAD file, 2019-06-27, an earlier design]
3D/bride.FCStd
144.0 x 20.0 x 20.0 mm

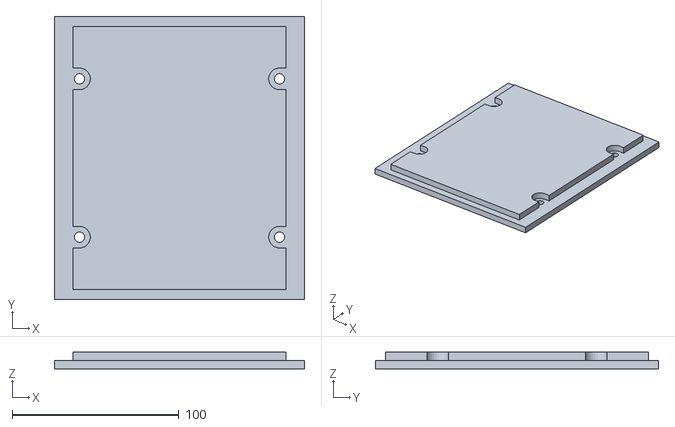
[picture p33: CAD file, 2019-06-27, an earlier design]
3D/arriere.stl
150.0 x 170.0 x 10.0

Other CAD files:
3D/brideV3.stl
3D/testfond.FCStd
3D/fix-brideV2.stl
3D/boitier2.stl
3D/Lormes.FCStd
3D/boitier.stl
3D/lormes1bis.stl
3D/Boitier demo salons/Panneau_Solaire.stl
3D/bride.stl
3D/bridev2.stl
3D/fix-bride.stl

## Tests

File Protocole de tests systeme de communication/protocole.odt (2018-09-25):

Protocole de test :

## Matériel :

- 2 cartes Arduino
- 1 LED + résistance
- 2 modules sans fil à tester

## 3 tests différents :

- Liaison « Au sol » environnement dégagé
- Liaison « Au sol » environnement urbain
- Liaison entre un point haut et le sol

Les tests devront être effectués plusieurs fois pour chaque capteurs et permettront de déterminer une portée moyenne utilisable dans laquelle la transmission de données pourra s’effectuer sans problèmes.

Lors de l’installation finale, il sera toutefois nécessaire de réaliser de nouveaux tests (programme spécifique) afin d’assurer le bon fonctionnement du système.

Les tests s’effectueront avec un programme spécifique sur les deux cartes Arduino (une émettrice et une réceptrice) les données seront transmises en continu entre les deux cartes et une LED indiquera la bonne réception des données.

Méthode alternative : une tablette ou un pc portable équipé de l’IDE arduino pourra récupérer les données de l’emmeteur via le moniteur série, ce qui permettra une meilleure visualisation

La carte émettrice sera positionnée, fixe, de manière a donner un point de repère. La seconde devra être transportée en s’éloignant de la première jusqu’à ce que le signal devienne altéré, puis ne soit plus du tout disponible.

La distance entre les deux Arduino pourra être calculée à l’aide des coordonnées GPS, et ces données seront centralisées dans un tableau afin de les comparer plus simplement.

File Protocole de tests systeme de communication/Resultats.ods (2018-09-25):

Technologie | Type de carte | Au sol / dégagé | Au sol / Urbain | Point haut / sol |  | Envoi | Réception
Radio | Module Radio HC-12 |  | ~130m max |  | Module Radio HC-12
Radio | NRF24L01 |  |  |  | NRF24L01 | NRF24_envoi.ino | NRF24_reception.ino
LoRa | shield LoRa Dragino | ~10m / 50m | 20m |  | shield LoRa Dragino | dragino-envoi.ino | Dragino-reception.ino
LoRa | AdaFruit RFM95W |  | ~700m |  | AdaFruit RFM95W | RFM95W_envoi.ino | RFM95W_reception.ino
xBee | xBee Pro S1 |  | 300m |  | xBee Pro S1 | xBee_envoi.ino | xBee_reception.ino

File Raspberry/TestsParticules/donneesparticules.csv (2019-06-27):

DEBUT!!!
DEBUT!!!
38.38 | 1.60
5.90 | 0.77
6.48 | 0.69
10.46 | 0.42
0.20 | 0.28
47.47 | 1.05
5.71 | 0.75
47.86 | 0.63
19.19 | 0.69
6.82 | 0.63
0.20 | 0.38
40.36 | 0.66
0.20 | 0.10
14.20 | 0.47
28.72 | 0.41
32.96 | 0.58
0.20 | 0.31
39.28 | 0.44
0.20 | 0.08
41.28 | 0.41
22.95 | 0.44
43.00 | 0.43
9.65 | 0.23
0.20 | 0.26
0.20 | 0.32
1.31 | 0.29
30.62 | 0.46
0.20 | 0.20
11.67 | 0.40
9.54 | 0.28
0.20 | 0.29
0.20 | 0.29
0.20 | 0.16
12.47 | 0.52
25.88 | 0.49
8.34 | 0.30
15.28 | 0.22
0.20 | 0.39
0.20 | 0.29
48.10 | 0.47
24.28 | 0.49
0.20 | 0.21
2.13 | 0.23
0.20 | 0.26
0.20 | 0.24
8.93 | 0.57
0.20 | 0.37
0.20 | 0.22
0.20 | 0.30
0.20 | 0.27
15.35 | 0.31
0.20 | 0.08
0.20 | 0.23
0.20 | 0.31
0.20 | 0.37
8.37 | 0.42
0.20 | 0.09
19.78 | 0.43
16.01 | 0.25
0.20 | 0.19
47.77 | 0.37
16.31 | 0.46
0.20 | 0.24
0.20 | 0.16
4.63 | 0.26
6.64 | 0.18
0.20 | 0.16
19.29 | 0.74
0.20 | 0.22
0.20 | 0.24
9.05 | 0.55
10.69 | 0.36
10.38 | 0.31
0.20 | 0.22
0.20 | 0.28
10.21 | 0.42
22.35 | 0.39
0.20 | 0.26
0.20 | 0.15
0.20 | 0.10
0.20 | 0.12
0.20 | 0.36
0.20 | 0.12
19.86 | 0.42
0.20 | 0.16
0.20 | 0.12
14.91 | 0.20
0.20 | 0.19
3.19 | 0.30
7.17 | 0.33
0.20 | 0.20
35.32 | 0.54
5.13 | 0.45
0.20 | 0.16
12.48 | 0.31
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

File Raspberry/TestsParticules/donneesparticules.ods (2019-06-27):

Heure | Pm10 | Pm25
18:02:00 | 0,2 | 0,28
18:08:00 | 0,2 | 0,38
18:10:00 | 0,2 | 0,1
18:14:00 | 0,2 | 0,31
18:16:00 | 0,2 | 0,08
18:21:00 | 0,2 | 0,26
18:22:00 | 0,2 | 0,32
18:25:00 | 0,2 | 0,2
18:28:00 | 0,2 | 0,29
18:29:00 | 0,2 | 0,29
18:30:00 | 0,2 | 0,16
18:35:00 | 0,2 | 0,39
18:36:00 | 0,2 | 0,29
18:39:00 | 0,2 | 0,21
18:41:00 | 0,2 | 0,26
18:42:00 | 0,2 | 0,24
18:44:00 | 0,2 | 0,37
18:45:00 | 0,2 | 0,22
18:46:00 | 0,2 | 0,3
18:47:00 | 0,2 | 0,27
18:49:00 | 0,2 | 0,08
18:50:00 | 0,2 | 0,23
18:51:00 | 0,2 | 0,31
18:52:00 | 0,2 | 0,37
18:54:00 | 0,2 | 0,09
18:57:00 | 0,2 | 0,19
19:00:00 | 0,2 | 0,24
19:01:00 | 0,2 | 0,16
19:04:00 | 0,2 | 0,16
19:06:00 | 0,2 | 0,22
19:07:00 | 0,2 | 0,24
19:11:00 | 0,2 | 0,22
19:12:00 | 0,2 | 0,28
19:15:00 | 0,2 | 0,26
19:16:00 | 0,2 | 0,15
19:17:00 | 0,2 | 0,1
19:18:00 | 0,2 | 0,12
19:19:00 | 0,2 | 0,36
19:20:00 | 0,2 | 0,12
19:22:00 | 0,2 | 0,16
19:23:00 | 0,2 | 0,12
19:25:00 | 0,2 | 0,19
19:28:00 | 0,2 | 0,2
19:31:00 | 0,2 | 0,16
19:33:00 | 0,2 | 0,34
19:36:00 | 0,2 | 0,35
19:38:00 | 0,2 | 0,24
19:42:00 | 0,2 | 0,18
19:46:00 | 0,2 | 0,26
19:47:00 | 0,2 | 0,17
19:48:00 | 0,2 | 0,31
19:49:00 | 0,2 | 0,25
19:50:00 | 0,2 | 0,09
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

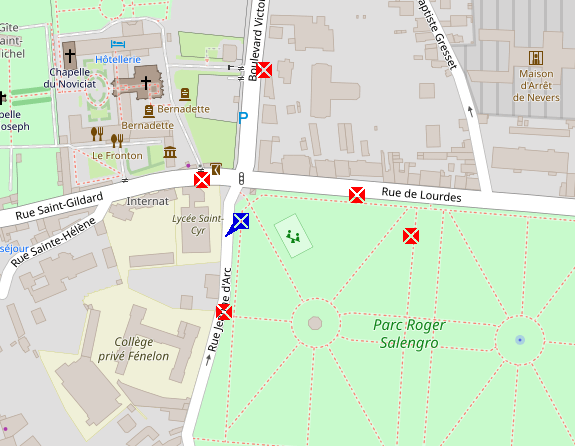
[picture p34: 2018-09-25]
Protocole de tests systeme de communication/carte/Images/hc12_1.png

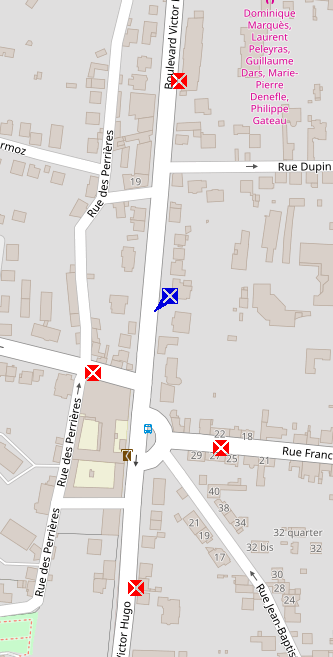
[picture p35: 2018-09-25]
Protocole de tests systeme de communication/carte/Images/xBee_1.png

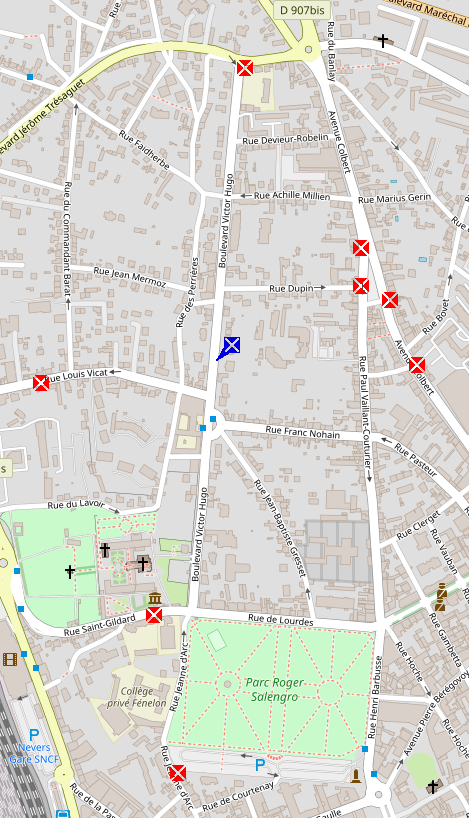
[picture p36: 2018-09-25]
Protocole de tests systeme de communication/carte/Images/LoRa-Adafruit_1.png

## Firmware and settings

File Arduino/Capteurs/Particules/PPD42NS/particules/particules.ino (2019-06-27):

#include "math.h"

int pin = 6;
unsigned long duration;
unsigned long starttime;
unsigned long sampletime_ms = 30000;//sampe 30s ;
unsigned long lowpulseoccupancy = 0;
float ratio = 0;
float concentration = 0;
float concentrationm3 = 0;
float pm25 = 0;
float pm10 = 0;





void setup() {
 Serial.begin(9600);
 pinMode(8,INPUT);
 starttime = millis();//get the current time;
}

void loop() {
 duration = pulseIn(pin, LOW);
 lowpulseoccupancy = lowpulseoccupancy+duration;
 if ((millis()-starttime) > sampletime_ms)//if the sampel time == 30s
 {
 ratio = lowpulseoccupancy/(sampletime_ms*10.0); // Integer percentage 0=>100
 concentration = 1.1*pow(ratio,3)-3.8*pow(ratio,2)+520*ratio+0.62; // using spec sheet curve
 
 concentrationm3 = (1.1*pow(ratio,3)-3.8*pow(ratio,2)+520*ratio+0.62)/0.000283168;
 pm10 = concentrationm3 * 0.00014356324;



    double r10 = 2.6 * pow(10, -6);
    double pi = 3.14159;
    double vol10 = (4 / 3) * pi * pow(r10, 3);
    double density = 1.65 * pow(10, 12);
    double mass10 = density * vol10;
    double K = 3531.5;
    float PM10conc = (pm10) * K * mass10;


double DensityParticle = 1.65*pow(10,12); // Densité moyenne d'une particule en microgramme par mètre cube
double Conversion = 3531.5; // Conversion 0.001 cu ft (comptage du nb de particules par 0.001 cu ft) en m3 

double RayonPM10 = 2.6*pow(10,-6); // Rayon particules PM10 en m

double VolumePM10 = (4/3) * PI * pow(RayonPM10,3); // Volume d'une particule PM10 en m3
double MassePM10 = DensityParticle * VolumePM10; // Masse d'une particule PM10 en microgramme

double ConcentrationPM10 = concentration*Conversion*MassePM10; // Concentration de particules PM10 en microgramme par mètre cube

 
 Serial.print("concentration = ");
 Serial.print(concentration);
 Serial.print(" pcs/0.01cf - ");
 Serial.print(PM10conc);
 Serial.print(" pcs/m3 - ");
 Serial.print(pm10);
 Serial.print(" ug/m3"); 
 Serial.print(ConcentrationPM10);
 Serial.println(" ug/m3"); 
 Serial.println("\n");
 lowpulseoccupancy = 0;
 starttime = millis();
 }
}

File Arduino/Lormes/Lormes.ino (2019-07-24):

#include <SPI.h>
#include <RH_RF95.h>

#include "DHT.h"

#include "Seeed_BMP280.h"
#include <Wire.h>


#define DHTPIN 6    
#define DHTTYPE DHT22  

#define RFM95_CS      4
#define RFM95_INT     3
#define RFM95_RST     2
#define LED           13

// Paramétrage de la fréquence du module LoRa
#define RF95_FREQ 868.0

// Singleton instance of the radio driver
RH_RF95 rf95(RFM95_CS, RFM95_INT);

DHT dht(DHTPIN, DHTTYPE);

BMP280 bmp280;

int idNode = 1;
int idTemperature = 1;
int idHumidite = 4;
int idPression = 2;

void setup() 
{
  pinMode(RFM95_RST, OUTPUT);
  digitalWrite(RFM95_RST, HIGH);

  Serial.begin(115200);

  dht.begin();

  if(!bmp280.init()) {
    Serial.println("Device not connected or broken!");
  }
  
  while (!Serial) {
    delay(1);
  }

  delay(100);

  Serial.println("Feather LoRa TX Test!");

  // manual reset
  digitalWrite(RFM95_RST, LOW);
  delay(10);
  digitalWrite(RFM95_RST, HIGH);
  delay(10);

  while (!rf95.init()) {
    Serial.println("LoRa radio init failed");
    while (1);
  }
  Serial.println("LoRa radio init OK!");

  // Defaults after init are 434.0MHz, modulation GFSK_Rb250Fd250, +13dbM
  if (!rf95.setFrequency(RF95_FREQ)) {
    Serial.println("setFrequency failed");
    while (1);
  }
  Serial.print("Set Freq to: "); Serial.println(RF95_FREQ);

  // Puissance du module (entre 5 et 23 dBm)
  rf95.setTxPower(23, false);
}

void loop()
{
  delay(10000); // attendre 10 secondes entre chaque envoi

  float humidite = dht.readHumidity();
  float temperature1 = dht.readTemperature();

  float pression = bmp280.getPressure();
  float temperature2 = bmp280.getTemperature();

  float temperature = (temperature1 + temperature2)/2;

char radiopacket[50];

  String chaineEnvoi = "$";
  chaineEnvoi += idNode;
  chaineEnvoi += ";";
  
  chaineEnvoi += idTemperature;
  chaineEnvoi += "=";
  chaineEnvoi += temperature;
  chaineEnvoi += ";";

  chaineEnvoi += idHumidite;
  chaineEnvoi += "=";
  chaineEnvoi += humidite;
  chaineEnvoi += ";";

  chaineEnvoi += idPression;
  chaineEnvoi += "=";
  chaineEnvoi += pression;
  chaineEnvoi += "$";

  
  chaineEnvoi.toCharArray(radiopacket, 50);
  // char radiopacket[50] = "$"+idNode+";"+idTemperature+"="+temperature+";"+idHumidite+"="+humidite+";65=23456$";

  Serial.print("Sending "); Serial.println(radiopacket);

  delay(10);
  rf95.send((uint8_t *)radiopacket, 50);

  delay(10);
  rf95.waitPacketSent();

}

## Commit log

2018-02-12 Ajout comparatif / Schémas
    [comparatif technos sans fil.ods]
2018-06-01 Nettoyage + integration de la carte au site + modification des styles des boutons d'OpenLayers
2018-06-19 Nettoyage dans les fichiers
2018-06-28 Création automatique csv / Modification mise en forme documentation
    [Capteurs.ods]
2018-06-28 Mise en forme partie Documentation / Readme
    [comparatif technos sans fil.ods]
2018-06-28 Ajout de la base de donnée
2018-06-28 Readme principal
    [comparatif_technos.csv]
2018-07-02 Rangement / tri documentation
    [Capteurs.ods, comparatif technos sans fil.ods, comparatif_technos.csv]
2018-07-06 Modification page Data / Ajout graphique + affichage des données des capteurs
2018-07-16 Ajout de types de graphiques à implémenter
2018-07-31 Ajout Arduino
2018-07-31 Documentation module radio HC-12 + Code Arduino
2018-08-03 Transmission de données module HC-12 + doc
2018-08-27 Changement mot de passe bdd
2018-09-03 Ajout du nom du node dans le dropdown de la vue data
2018-09-24 Librairies Arduino
2018-09-25 Tests et résultats
    [Resultats.ods]
2019-02-12 saisir le message de validation pour vos modifications. Les lignes
    [configuration.h]
2019-05-09 Initialisation centrage de la carte automatisée
2019-05-15 Correction styles des bulles sur la carte
2019-05-15 Corrections / choix du mois de début / fin
2019-05-17 Corrections fin + nouvelles variables pour personaliser les données générées
2019-05-28 Modèles 3D pour boite capteurs
    [Lormes.FCStd, lormes1.stl, lormes1bis.stl]
2019-06-27 Plus de batterie
    [Lormes.FCStd, arriere.stl, bOITIERMODIF.stl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]
2019-08-26 Mise en forme documentation transfert de donées
2019-08-27 Documentation capteurs + nettoyage code Arduino
    [comparatif technos sans fil.ods, comparatif_technos.csv, configuration.h]
